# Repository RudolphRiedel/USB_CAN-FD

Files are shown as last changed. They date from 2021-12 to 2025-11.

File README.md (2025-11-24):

# Hardware
This is an Open Source Hardware USB to CAN-FD interface.
The design goal of this PCB was to provide two isolated CAN-FD channels capable of 8MBit/s for the data phase.

## D5035-01
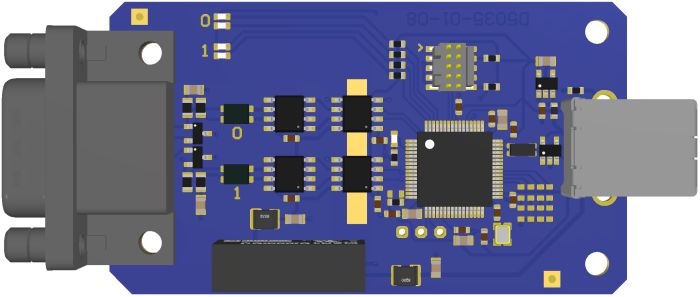
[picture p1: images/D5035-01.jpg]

The PCBs D5035-01-xx are based on the ATSAME51J microcontroller from Microchip.
Any ATSAME51J1x-Axx can be used, so every variant in TQFP-64, the bootloader and the firmware work on all three memory sizes.

D5035-01-08 likely is the final version.
I switched from using CAN-FD transceivers to CAN-SIC transceivers.

There is a full BOM included now: D5035-01_BOM_Release.xlsx
It has order codes from Mouser as example and the sum of the parts I selected came out as just below 29 Euros exclucding taxes when ordering only parts for a single unit.
The most expensive parts are the digital isolators, the controller, the CAN transceivers, the DCDC converter and the oscillator, which already cover more than half of the BOM costs which leaves no room to bringt the costs down - except when buying in bulk.
Cheaping out on components like the D-Sub 9 would be possible, but I really advise against it, I already chose a component that is inexpensive for it's specification, it is important for the application to use a gold plated D-Sub with at least 200 mating cycles.

The board is 69 mm x 39 mm.

## D5035-01-20
Almost the same as D5035-01-08, but with an USB-C connector.

## D5035-03
The PCB D5035-03-01 is designed as a carrier board for the Teensy 4.0.
This is more a prove of concept, a child of the current chip-shortage.

And it works, but it turned out to be rather fidgety to access the pins
for the single CAN-FD available and the 61 mm x 33 mm case does not work well for this version.

## D5035-05
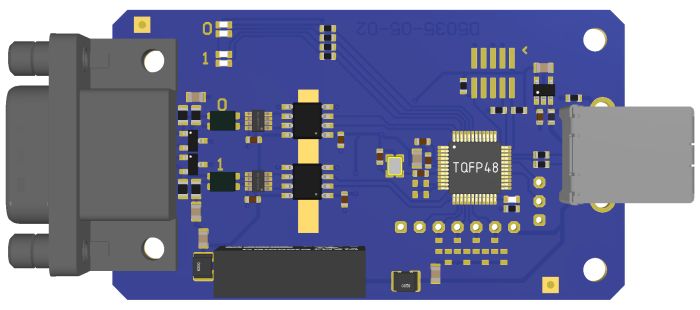
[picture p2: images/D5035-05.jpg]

The PCBs D5035-05-xx are based on the STM32G0B1CET6 microcontroller.
The board is slightly larger at 69 mm x 39 mm.

## Case
There are two versions of a 3D printable case available in this repository:
D5035-01 - 39 mm x 74.1 mm
D5035-05 - 45 mm x 82.14 mm

Assembly requires two press-fit light pipes for the status LEDs, two lengths of black 3.2 mm heat shrink tubing to hold the light pipes in place and four countersunk screws.

LFB063CTP - DigiKey LFB063CTP-ND - Mouser 593-LFB063CTP
M3 x 16 mm, countersunk, preferably Torx / A2 (ISO 14581)

## Whats next
There is an idea for a PCB with a different controller but unfortunately these are not
available anywhere, so this got pushed back.

## Beyond CAN
A board with 100Base-T1 or 10Base-T1S is also something we think about.

## Firmware
The open source firmware for this project is here: https://github.com/jgressmann/supercan

## Windows application
An open source Windows application that works with this interface is here: https://github.com/TDahlmann/canpp

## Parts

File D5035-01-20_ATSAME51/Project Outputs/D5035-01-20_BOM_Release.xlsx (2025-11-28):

Comment | Description | Designator | Footprint | Number | Mouser | Price [EUR] | Price sum | Alternative Part
10n | X7R/10V/10% | C100 | 0603 (1608 Metric) | 1 | 710-885012206014 | 0.095 | 0.095
100n | X7R/50V/10% | C101, C103, C104, C106, C107, C108, C111, C113, C115, C117, C118, C120 | 0603 (1608 Metric) | 12 | 603-CC603KRX7R9BB104 | 0.023 | 0.276
4µ7 | X5R/25V/10% | C102, C105, C109, C110, C112, C116 | 0805 (2012 Metric) | 6 | 187-CL21A475KAQNNNG | 0.095 | 0.57
4n7 | X7R/200V/10% | C114, C119 | 0805 (2012 Metric) | 2 | 187-CL21B472KDCNNNC | 0.095 | 0.19
D1213A-02SM-7 | ESD Protection Diode Array | D100 | SOT23-5 | 1 | 621-D1213A-02SM-7 | 0.292 | 0.292 | WE 824011
PESD1CAN | ESD Protection Diode Array | D105, D107 | SOT23 | 2 | 511-ESDCAN01-2BLY | 0.15 | 0.3 | 771-PESD1CAN-T/R
green | 100+ mcd | D106, D108, D110 | 0603 (1608 Metric) | 3 | 710-150060GS75000 | 0.138 | 0.414 | 859-LTST-C191TGKT
red | 100+ mcd | D109, D111 | 0603 (1608 Metric) | 2 | 710-150060RS75000 | 0.138 | 0.276 | 859-LTST-C190KRKT
TG2520SMN16.0000M-MCGNNM | Oscillator 16MHz, 3.3V, 0.5PPM | G100 | 2,5mm x 2,0mm | 1 | 732-2520SMN16MCGNNM0 | 0.628 | 0.628
BBPY0016080301Y00 | Ferrite Bead | L100 | 0603 (1608 Metric) | 1 | 710-742792641 | 0.143 | 0.143 | WE 742792641
PE-1206CCMC900STS | USB Common Mode Choke | L101 | 3216 | 1 | 673-PE-1206CCMC900ST | 0.542 | 0.542 | WE 744232090
82103C | 10µH/500mA Power Inductor | L102, L103 | 1210 (3225 Metric) | 2 | 963-LBC3225T100KR | 0.103 | 0.206 | LBC3225T100KR
SRF3225TAC-101Y | CAN Commen Mode Choke | L104, L105 | 1210 (3225 Metric) | 2 | 652-SRF3225TAC-101Y | 0.507 | 1.014
10k | 1%/TK100 | R111, R112, R115, R116 | 0603 (1608 Metric) | 4 | 603-RT0603FRE1310KL | 0.095 | 0.38
2k | 1%/TK100 | R105, R107 | 0603 (1608 Metric) | 2 | 594-MCT06030C2001FP5 | 0.095 | 0.19
1k | 1%/TK100 | R106, R108 | 0603 (1608 Metric) | 2 | 603-AT0603FRE071KL | 0.093 | 0.186
4k7 | 1%/TK100 | R109, R110, R113, R114, R100, R118 | 0805 (2012 Metric) | 6 | 603-RT0805FRE074K7L | 0.095 | 0.57
ATSAME51J18A-AU | MicroController, CAN-FD/USB | U100 | TQFP64-0.5mm | 1 | 556-ATSAME51J18AAU | 4.76 | 4.76 | ATSAME51J19A-AU
MIC5317-3.3YD5 | LDO, 3.3V, 150mA | U101 | SOT23-5 | 1 | 998-MIC5317-3.3YD5TR | 0.215 | 0.215
TEA 1-0505E | Isolated DC/DC 1W, 5V in, 5V out, 200mA | U102 | 4Pin SIP | 1 | 495-TEA1-0505E | 1.44 | 1.44 | MER1S0505SC
TCAN1462VDRQ1 | CAN SIC Transceiver 8 Mb/s | U103, U105 | SO8 | 2 | 595-TCAN1462VDRQ1 | 1.11 | 2.22 | TCAN1462DRQ1
SI8621EC-B-IS | Digital Isolator, 3.75kV, 150 Mb/s | U104, U106 | SO8 | 2 | 634-SI8621EC-B-ISR | 2.2 | 4.4
UJ20-C-H-G-SMT-1-P16-TR | USB Type C Connector, 16P | X100 | USB-C | 1 | 179-UJ20CHGSMT1P16TR | 0.456 | 0.456
D09P13A4PV00LF | D-Sub 9, Female, Right Angle, 200+ Mating cycles | X102 | D-Sub | 1 | 649-D09P13A4PV00LF | 1.36 | 1.36 | D09P13B6GV00LF
SWD | SMD pin header | X104 | 2x5 1,27mm | 1 | 649-200211210010C1LF | 0.662 | 0.662 | 649-221121-00010T4LF
LFB063CTP | Light Pipe | Mechanical | 15.9 mm x 2.84 mm | 2 | 593-LFB063CTP | 0.645 | 1.29
M3x16 | Screw ISO 14581 – countersunk, Torx, A2 | Mechanical |  | 4
D5035-02_top.stl | Case, 3D printed | Mechanical | 82 mm x 45 mm x 17 mm | 1
D5035-02_bottom.stl | Case, 3D printed | Mechanical | 82 mm x 45 mm x 12 mm | 1
 |  |  |  |  |  |  | 23.075
prices: | worst case, single unit | Checked: 2025-02-20
 |  | Checked: 2025-11-24

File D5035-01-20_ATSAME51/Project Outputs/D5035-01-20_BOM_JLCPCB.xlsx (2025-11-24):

Comment | Designator | Footprint | JLCPCB Part #
10n | C100 | 0603 | C57112
100n | C101, C103, C104, C106, C107, C108, C111, C113, C115, C117, C118, C120 | 0603 | C14663
4µ7 | C102, C105, C109, C110, C112, C116 | 0805 | C1779
4n7 | C114, C119 | 0805 | C1744
D1213A-02SM-7 | D100 | SOT23-5 | not available
PESD1CAN | D105, D107 | SOT23 | C343993
green | D106, D108, D110 | 0603 | C19171301
red | D109, D111 | 0603 | C2286
TG2520SMN16.0000M-MCGNNM | G100 | 2,5mm x 2,0mm | do not populate
BBPY0016080301Y00 | L100 | 0603 | not available
PE-1206CCMC900STS | L101 | 3216 | not available
82103C | L102, L103 | 3,2x2,5 mm | not available
SRF3225TAC-101Y | L104, L105 | 3225 | not available
10k | R111, R112, R115, R116 | 0603 | C25804
2k | R105, R107 | 0603 | C22975
1k | R106, R108 | 0603 | C21190
4k7 | R109, R110, R113, R114, R100, R118 | 0805 | C17673
SAME51J18A-AU | U100 | TQFP64-0.5mm | not available
MIC5317-3.3YD5 | U101 | SOT23-5 | not available
TEA 1-0505E | U102 | 4Pin SIP | not available
TCAN1462VDRQ1 | U103, U105 | SO8 | not available
SI8621EC-B-IS | U104, U106 | SO8 | (C461877)-outofstock
USB-C | X100 | USB-C | C2765186
9651226803 | X102 | D-Sub | do not populate
SWD | X104 | 2x5 1,27mm | do not populate

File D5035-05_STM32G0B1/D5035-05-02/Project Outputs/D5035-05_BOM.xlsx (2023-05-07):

Comment | Designator | Footprint | JLCPCB Part #
10n | C100 | 0603 | C57112
100n | C101, C102, C105, C106, C111, C112, C114, C115 | 0603 | C14663
4µ7 | C103, C104, C107, C108 | 0805 | C1779
4n7 | C110, C113 | 0805 | C1744
green | D104, D105, D107 | 0603 | C72043
red | D106, D108 | 0603 | C2286
PESD1CAN | D109, D110 | SOT23 | C343993
16MHz | G100 | 2,5mm x 2,0mm | do not populate
WE_742792641 | L100 | 0603 | do not populate
xx82103C | L101, L102 | 3,2x2,5 mm | do not populate
DLW32SH101XF2L‎ | L103, L104 | 3225 | do not populate
22R | R102, R103 | 0603 | C22950
10k | R105, R106, R115, R116, R120 | 0603 | C25804
2k | R111, R113 | 0603 | C22975
1k | R112, R114 | 0603 | C21190
4k7 | R118, R119, R121, R122 | 0805 | C17673
STM32G0B1CET6 | U100 | TQFP48-0.5mm
MIC5317-3.3YD5 | U101 | SOT23-5 | do not populate
MER1S0505SC | U102 | 4Pin SIP | do not populate
TCAN1044V | U103, U105 | SOT23-8 | do not populate
SI8621EC-B-IS | U104, U106 | SO8 | C461877
61729-0010BLF | X101 | USB-B | do not populate
9651226803 | X103 | D-Sub | do not populate

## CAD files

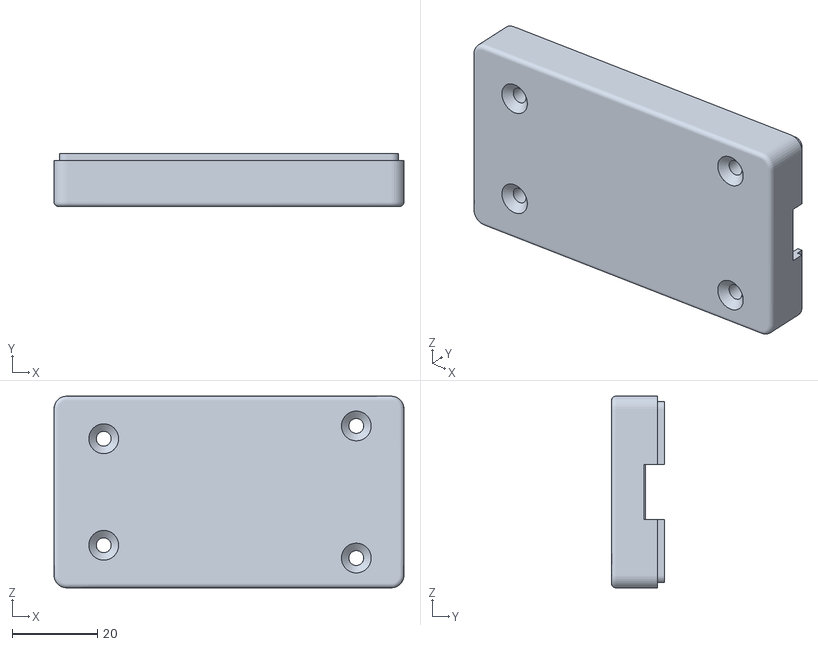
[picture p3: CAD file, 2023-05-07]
Case/D5035-05_bottom.stl
82.1 x 12.4 x 45.0

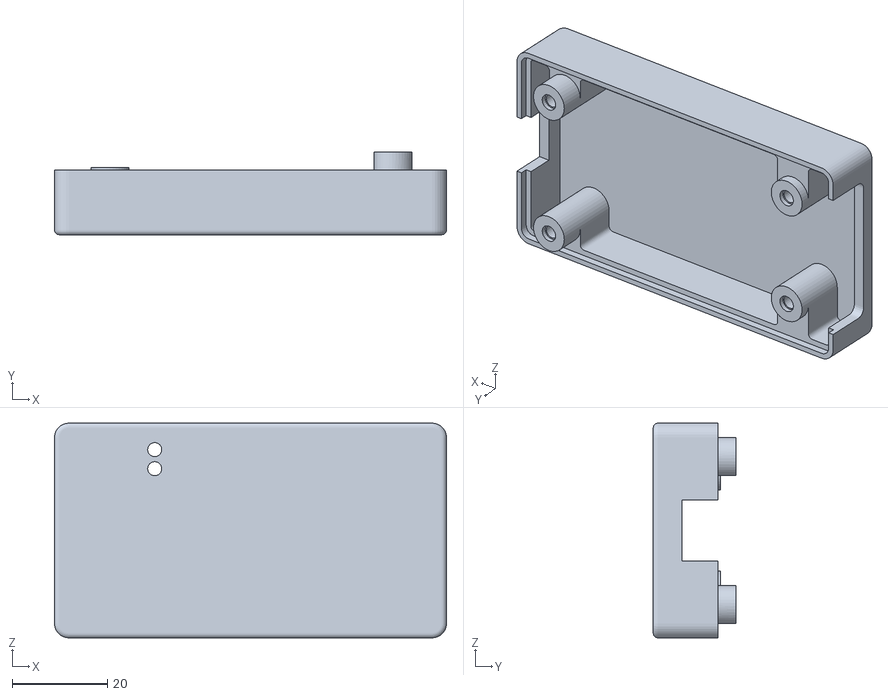
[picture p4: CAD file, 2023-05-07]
Case/D5035-05_top.stl
82.1 x 17.3 x 45.0

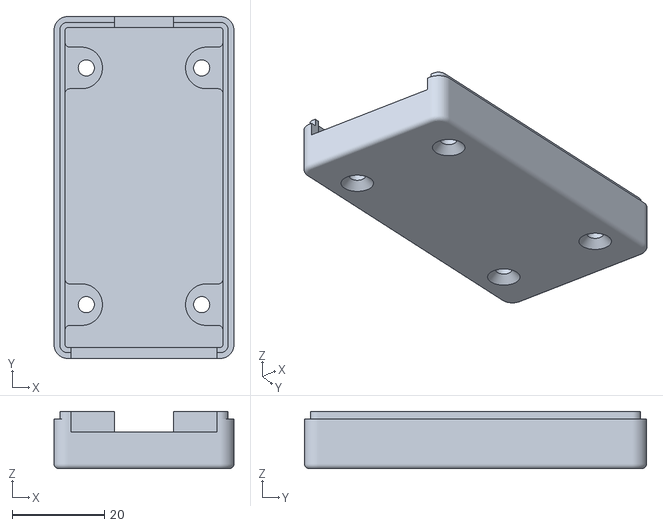
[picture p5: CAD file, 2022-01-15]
Case/D5035-01_bottom.stl
39.0 x 74.1 x 12.4

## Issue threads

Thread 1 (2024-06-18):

Can you please create a step-by-step firmware building and downloading?

toneytang, 2024-06-18:
Thank .

RudolphRrr, 2024-06-25:
Oh? Only saw this by chance, I have not seen a notification for this issue.

This repository does not have any frmware as this is a collaboration, check out: https://github.com/jgressmann/supercan

Downloading the firmware depends on the variant, for ATSAME51 I open Microchip Studio and flash the Supercan bootloader with either an Atmel ICE or a Segger JLink.
With the STM32G0B1 variant the firmware is just flashed with DFU-Util as the STM32 already has an USB bootloader built in.

zerotoney, 2024-10-10:
Thank you. I will give it a try. Still frustrated where to get the whole firmware project. New guy to STM.

toneytang, 2024-10-15:
https://github.com/jgressmann/tinyusb/tree/master/examples/device/supercan

Closed 2024-10-15.

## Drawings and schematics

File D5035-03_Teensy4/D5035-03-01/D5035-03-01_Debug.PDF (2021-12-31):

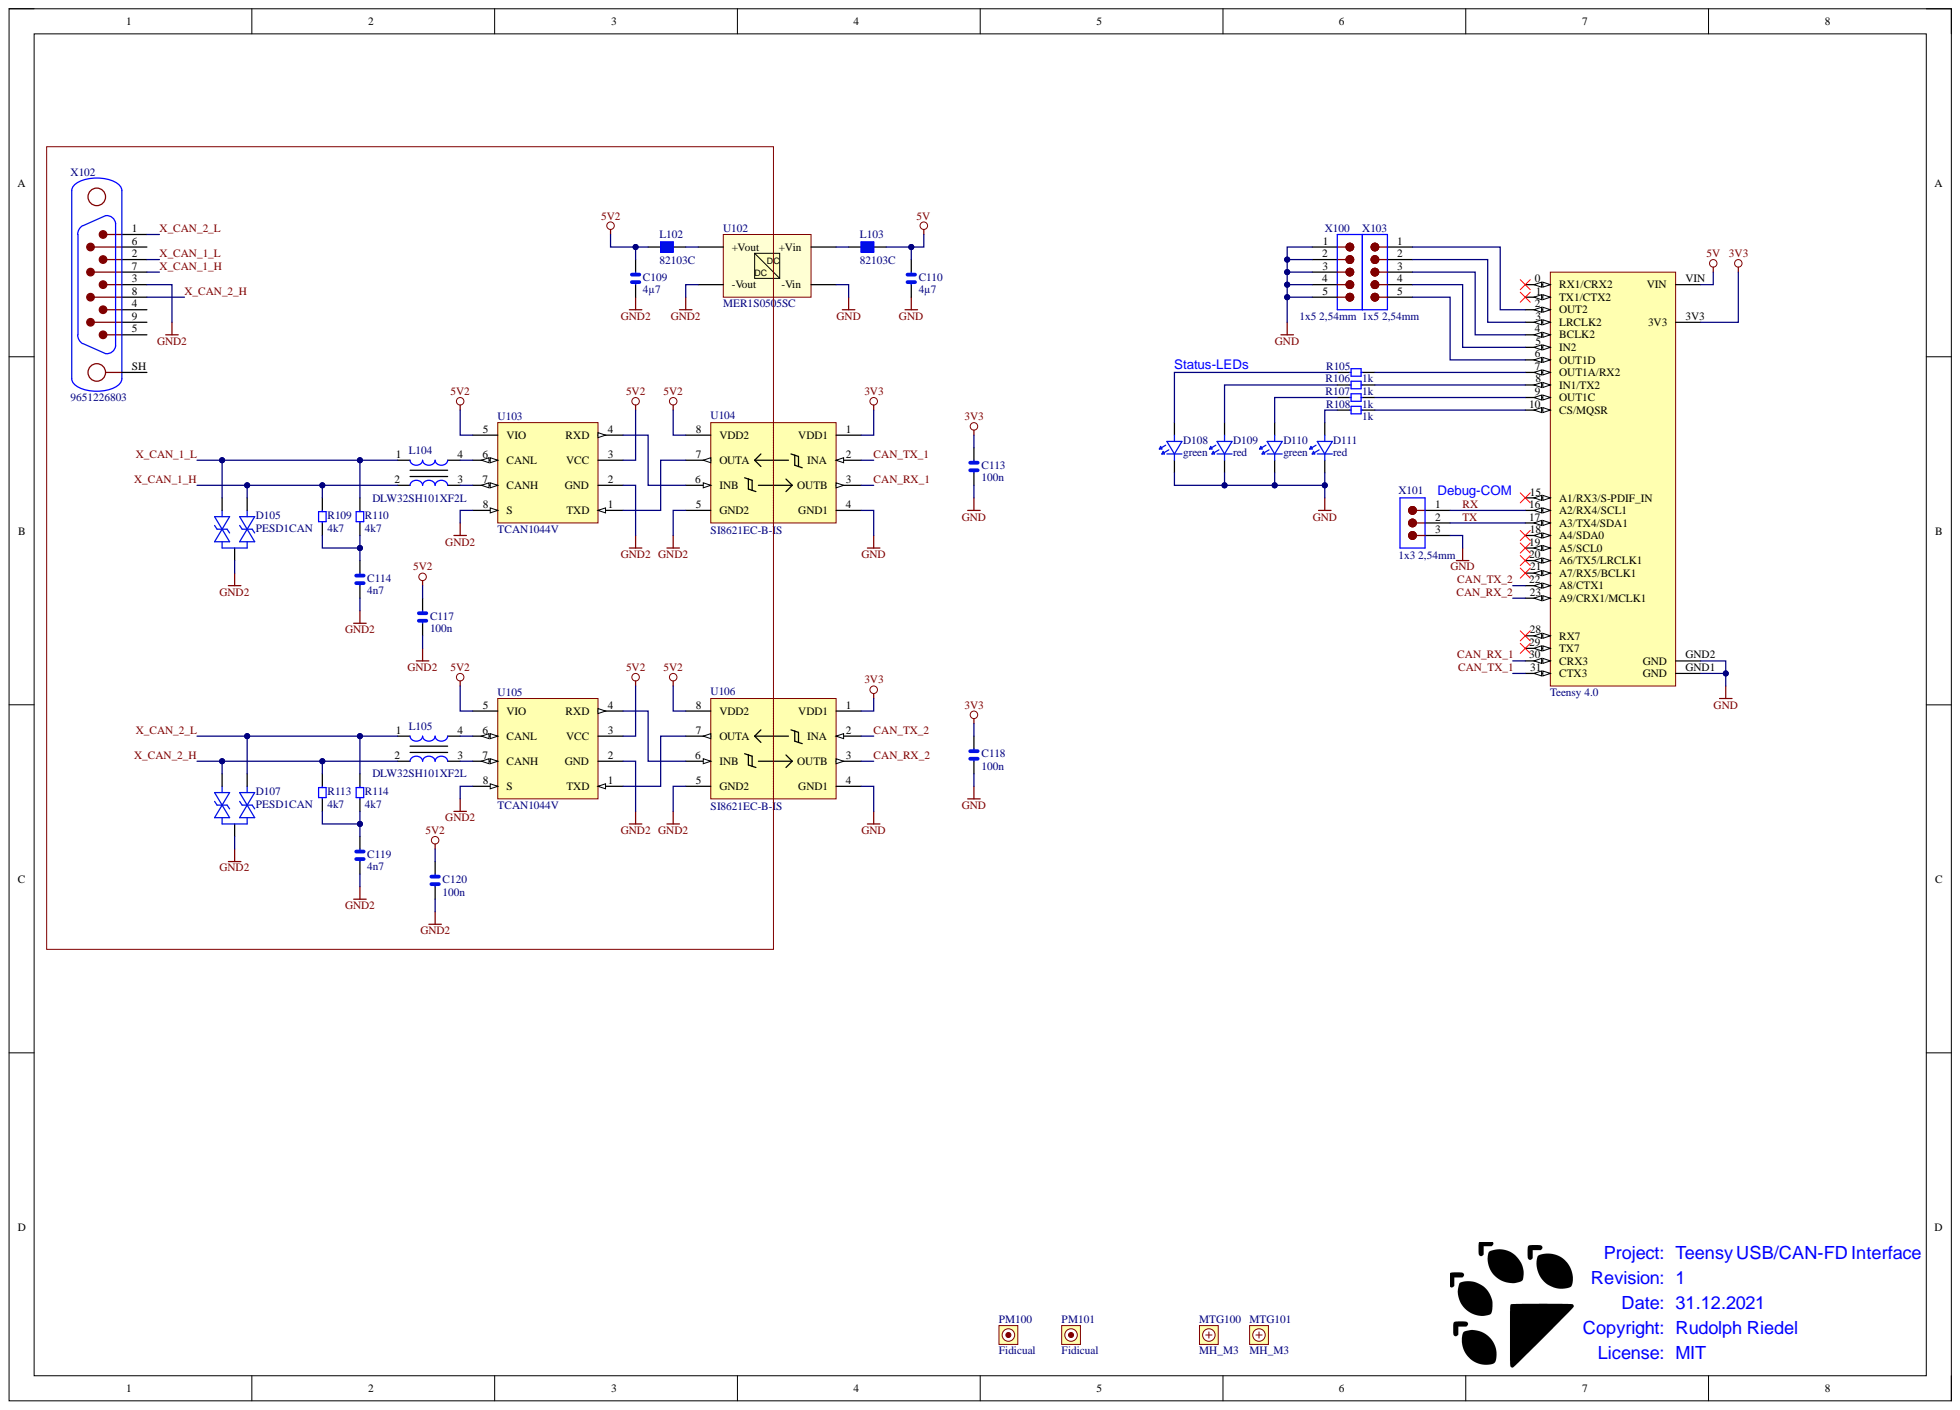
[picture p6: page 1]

LRCLK2 3

Project: Teensy USB/CAN-FD Interface
Revision: 1
Date: 31.12.2021
Copyright:
License:

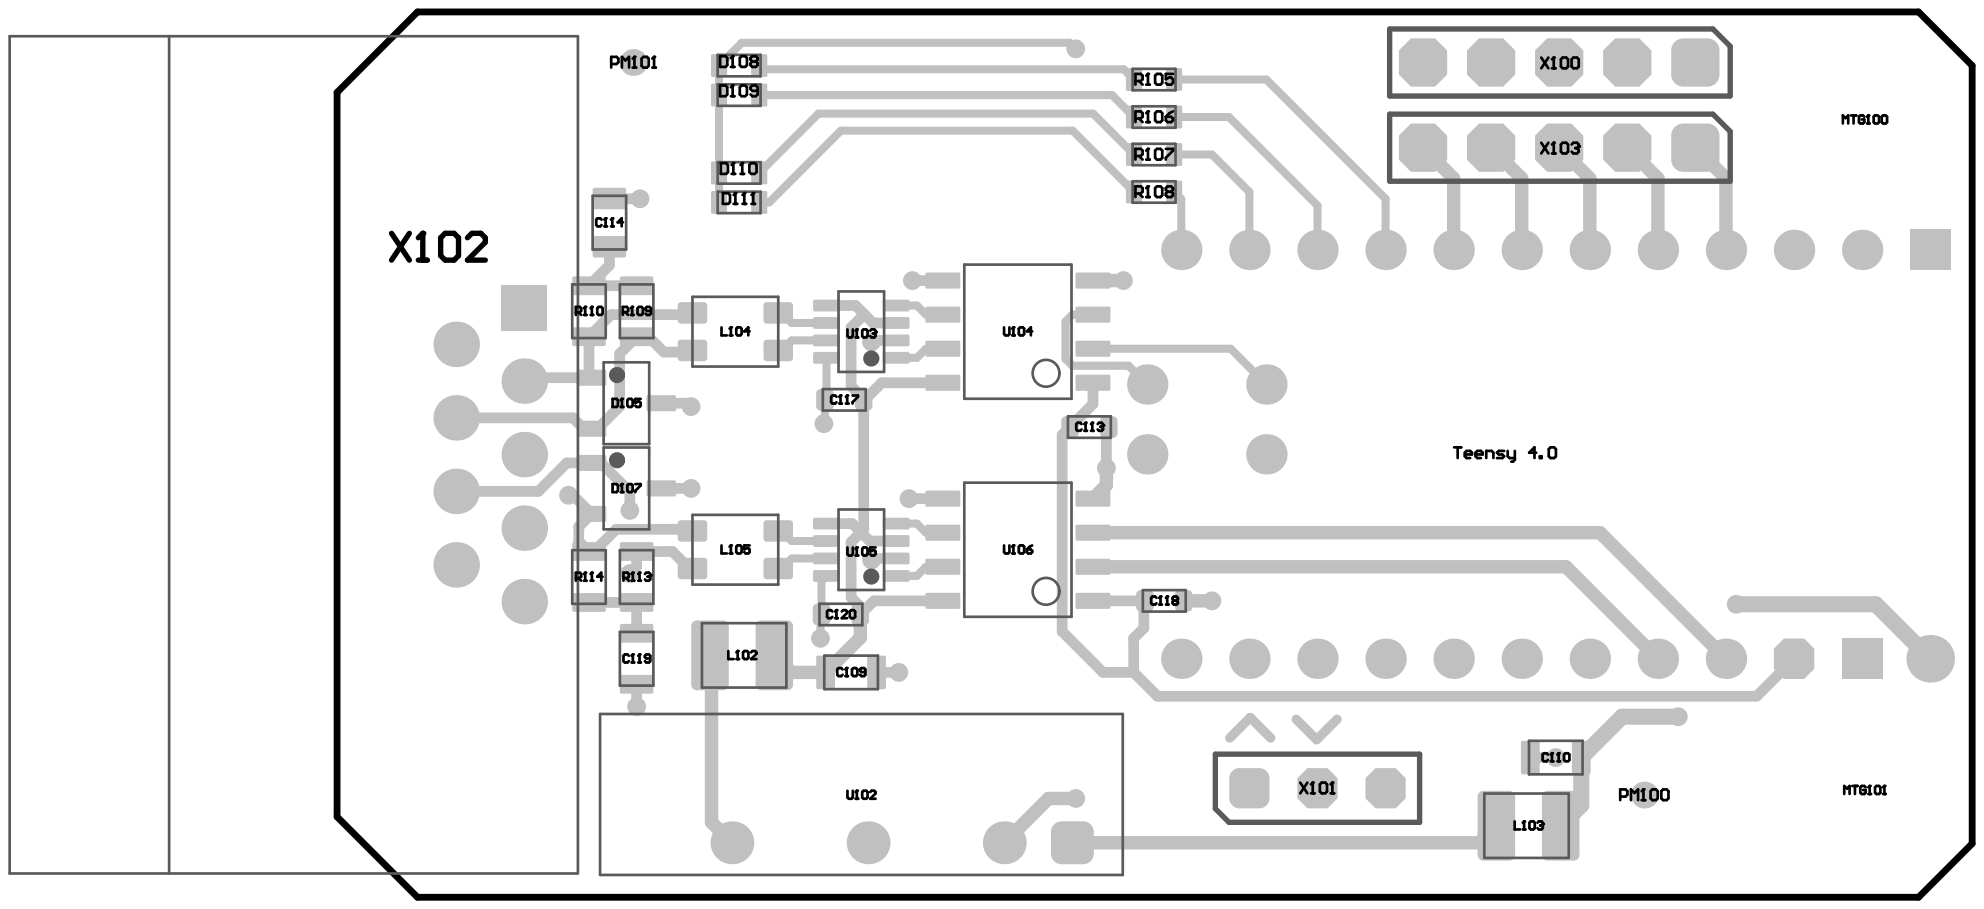
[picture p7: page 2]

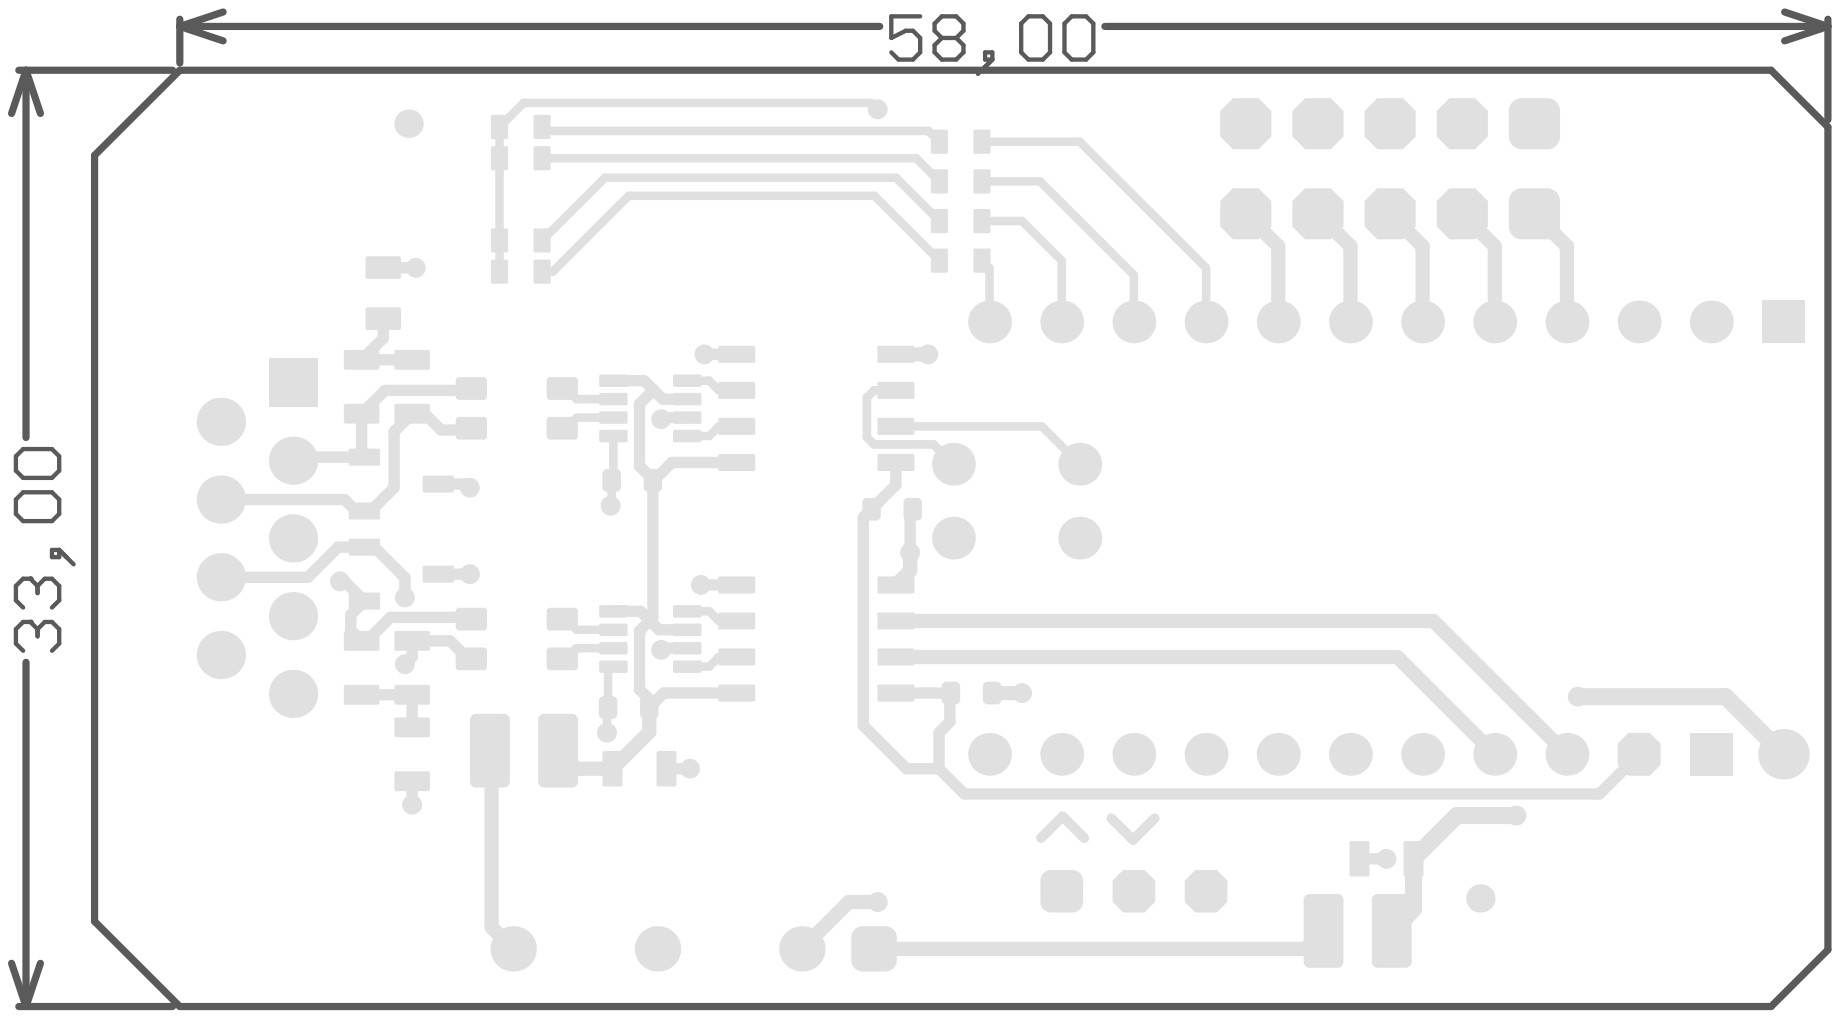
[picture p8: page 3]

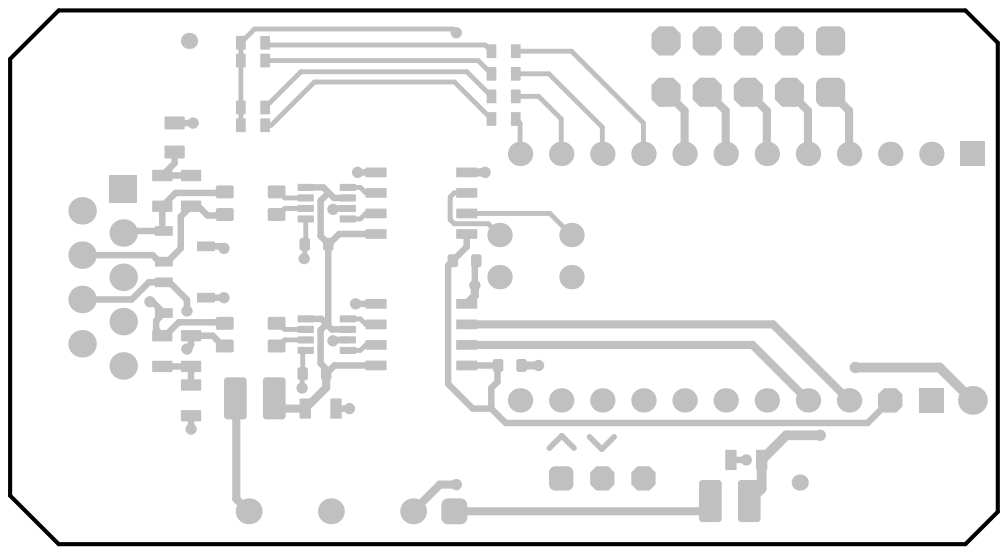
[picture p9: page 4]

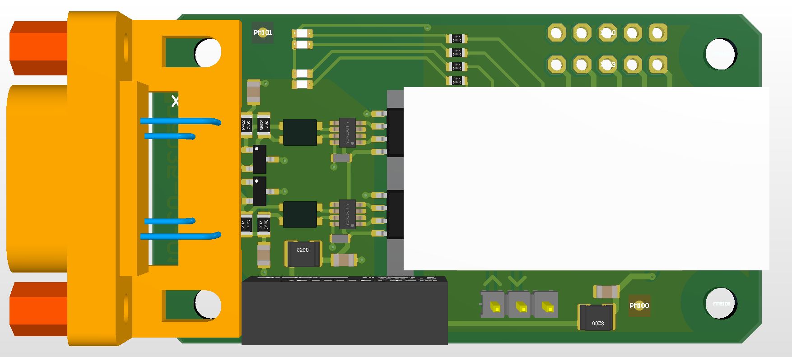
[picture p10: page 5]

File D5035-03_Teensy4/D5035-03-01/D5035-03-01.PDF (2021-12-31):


LRCLK2 3

Project: Teensy USB/CAN-FD Interface
Revision: 1
Date: 31.12.2021
Copyright:
License:




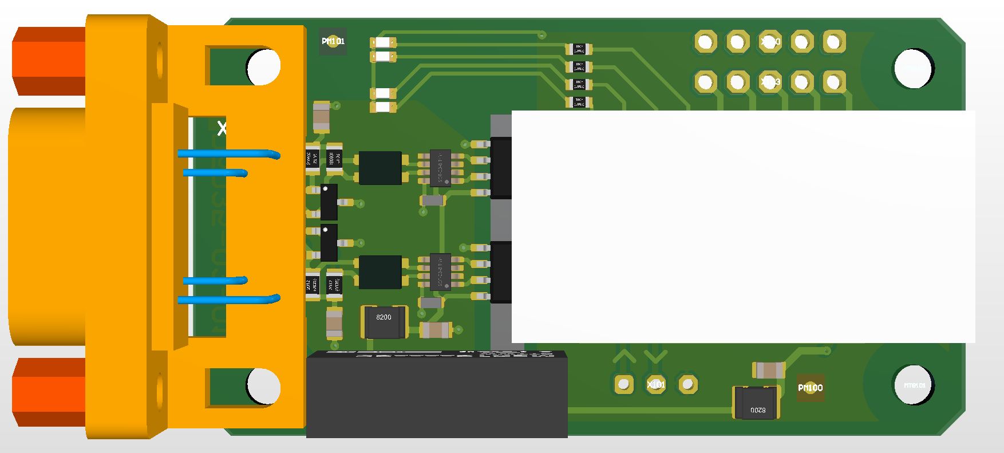
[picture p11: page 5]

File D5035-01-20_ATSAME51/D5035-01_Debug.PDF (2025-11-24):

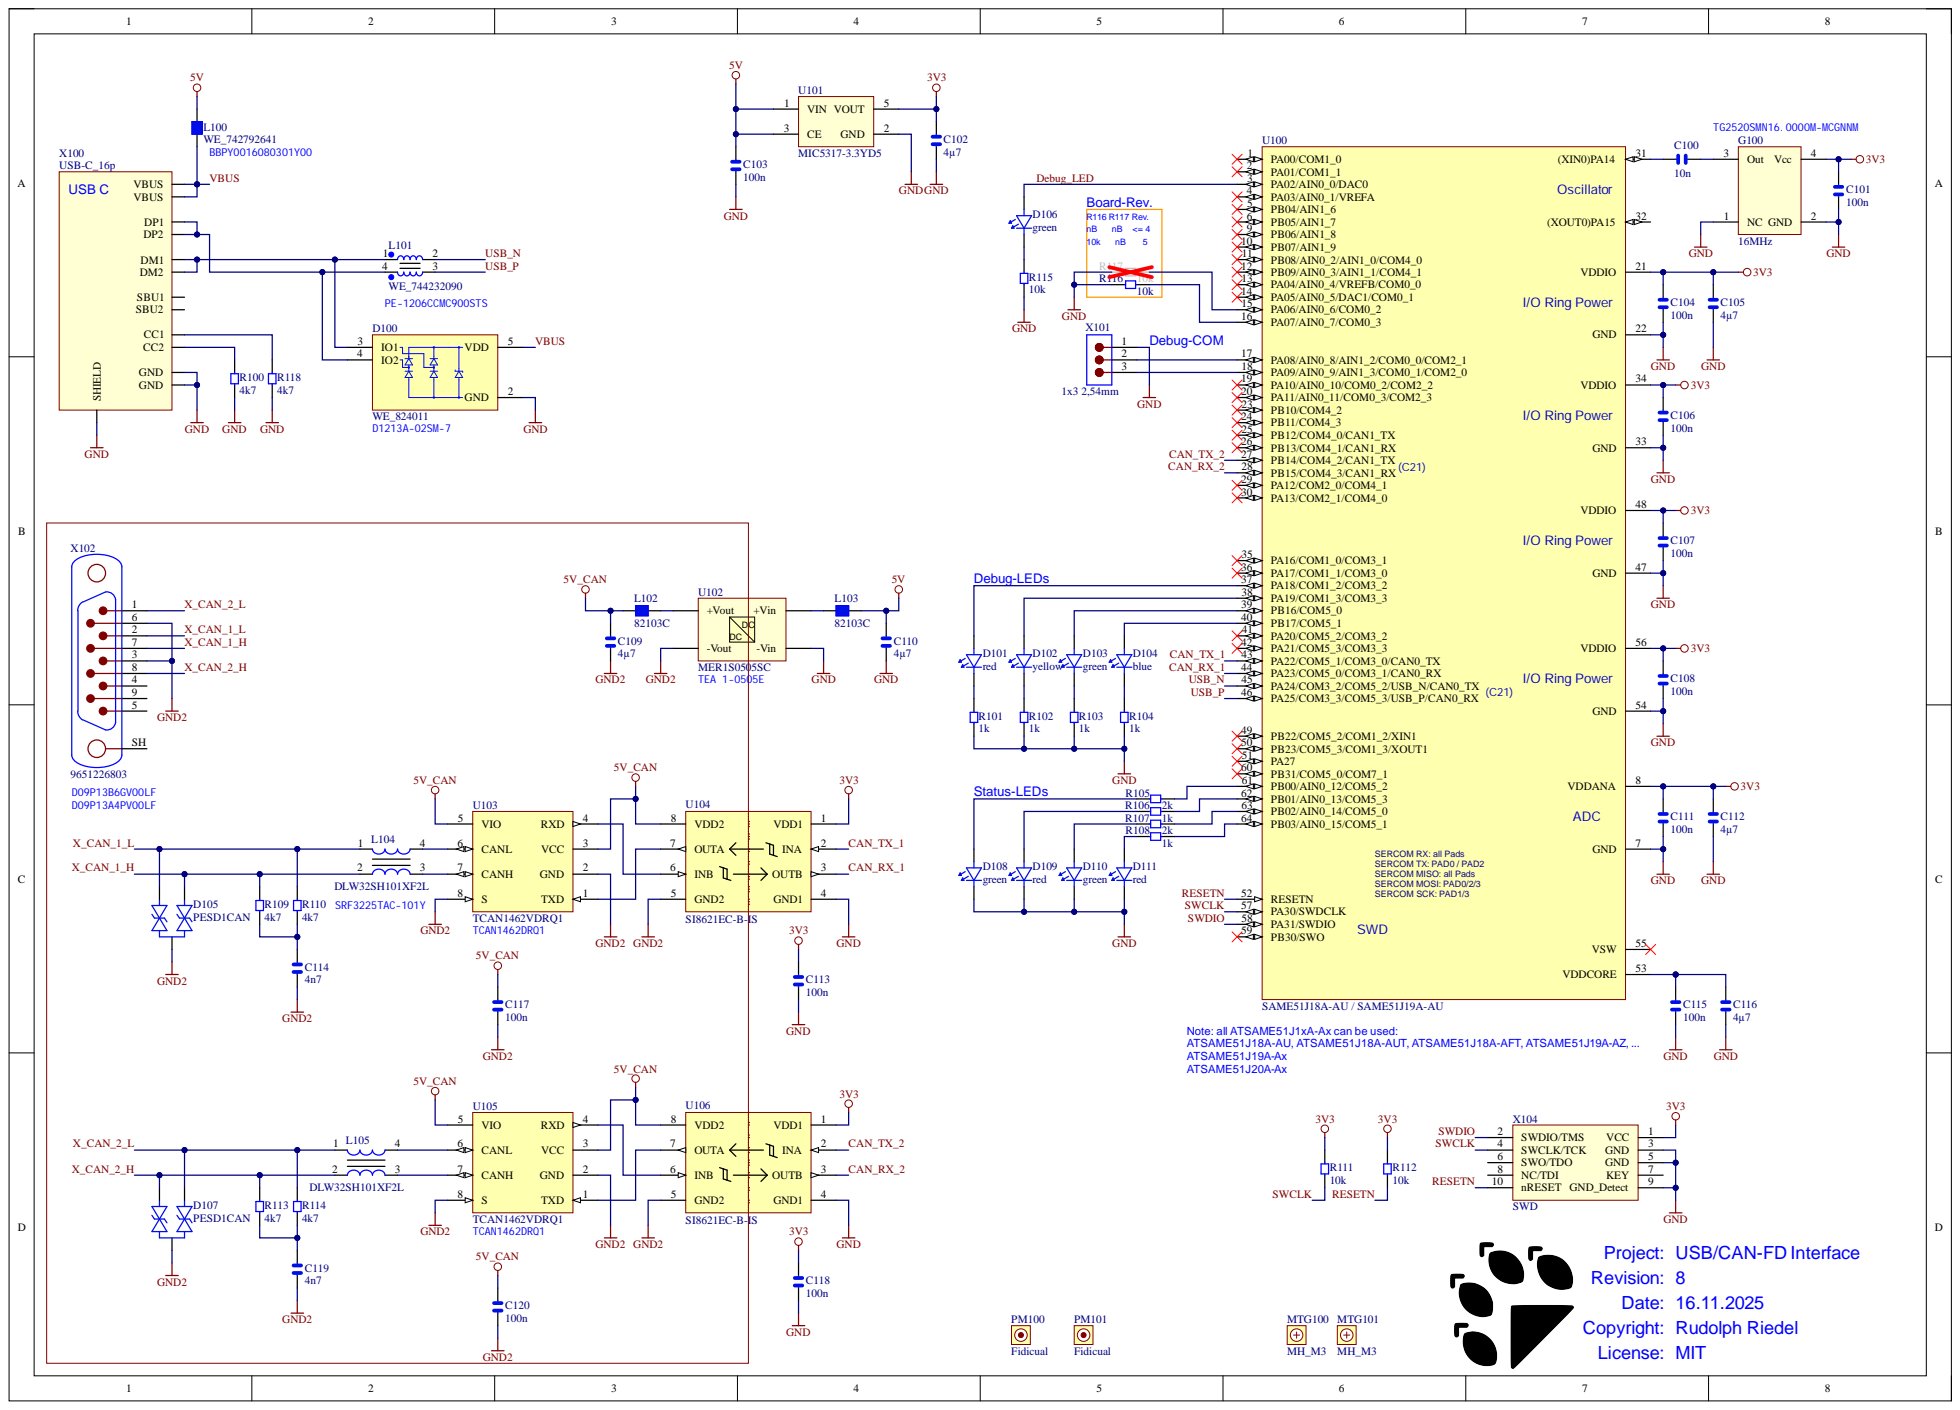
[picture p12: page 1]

PA19/COM1_3/COM3_3 38

PB17/COM5_1 40

PA21/COM5_3/COM3_3 42

5V_CAN

PB02/AIN0_14/COM5_0 63

SERCOM RX: all Pads
SERCOM TX: PAD0 / PAD2
SERCOM MISO: all Pads
SERCOM MOSI: PAD0/2/3
SERCOM SCK: PAD1/3

Note: all ATSAME51J1xA-Ax can be used:
ATSAME51J18A-AU, ATSAME51J18A-AUT, ATSAME51J18A-AFT, ATSAME51J19A-AZ, ...
ATSAME51J19A-Ax
ATSAME51J20A-Ax

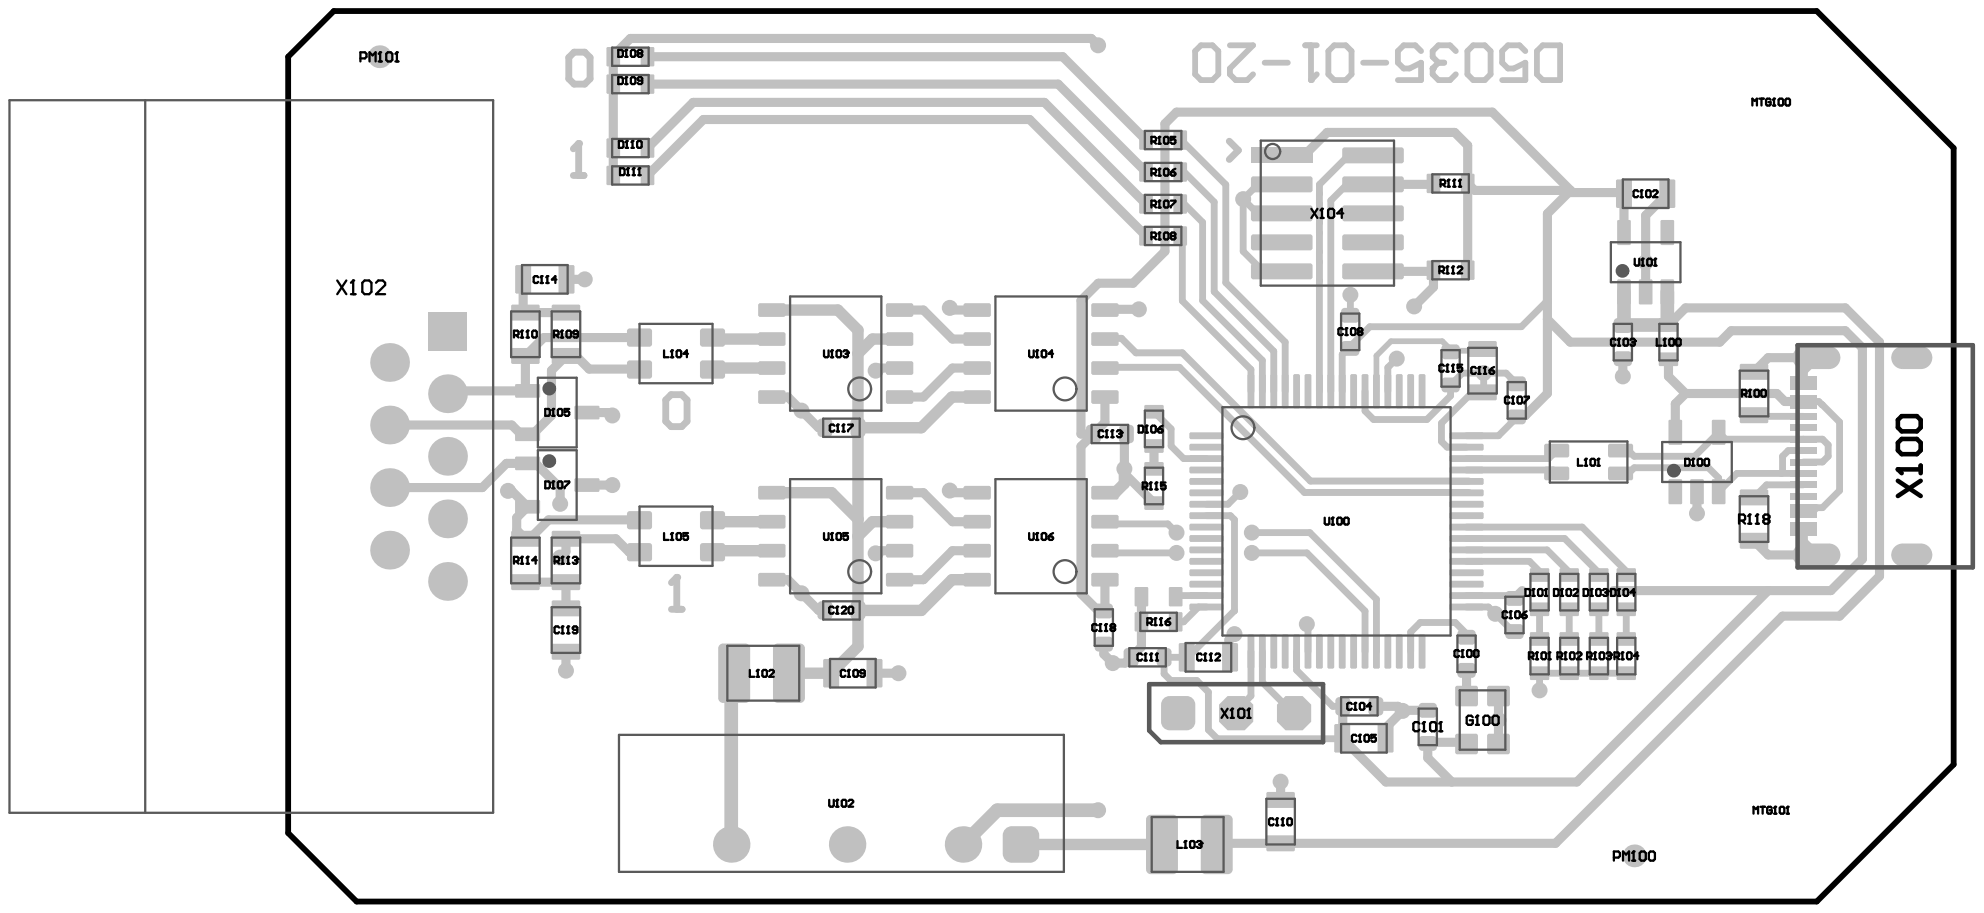
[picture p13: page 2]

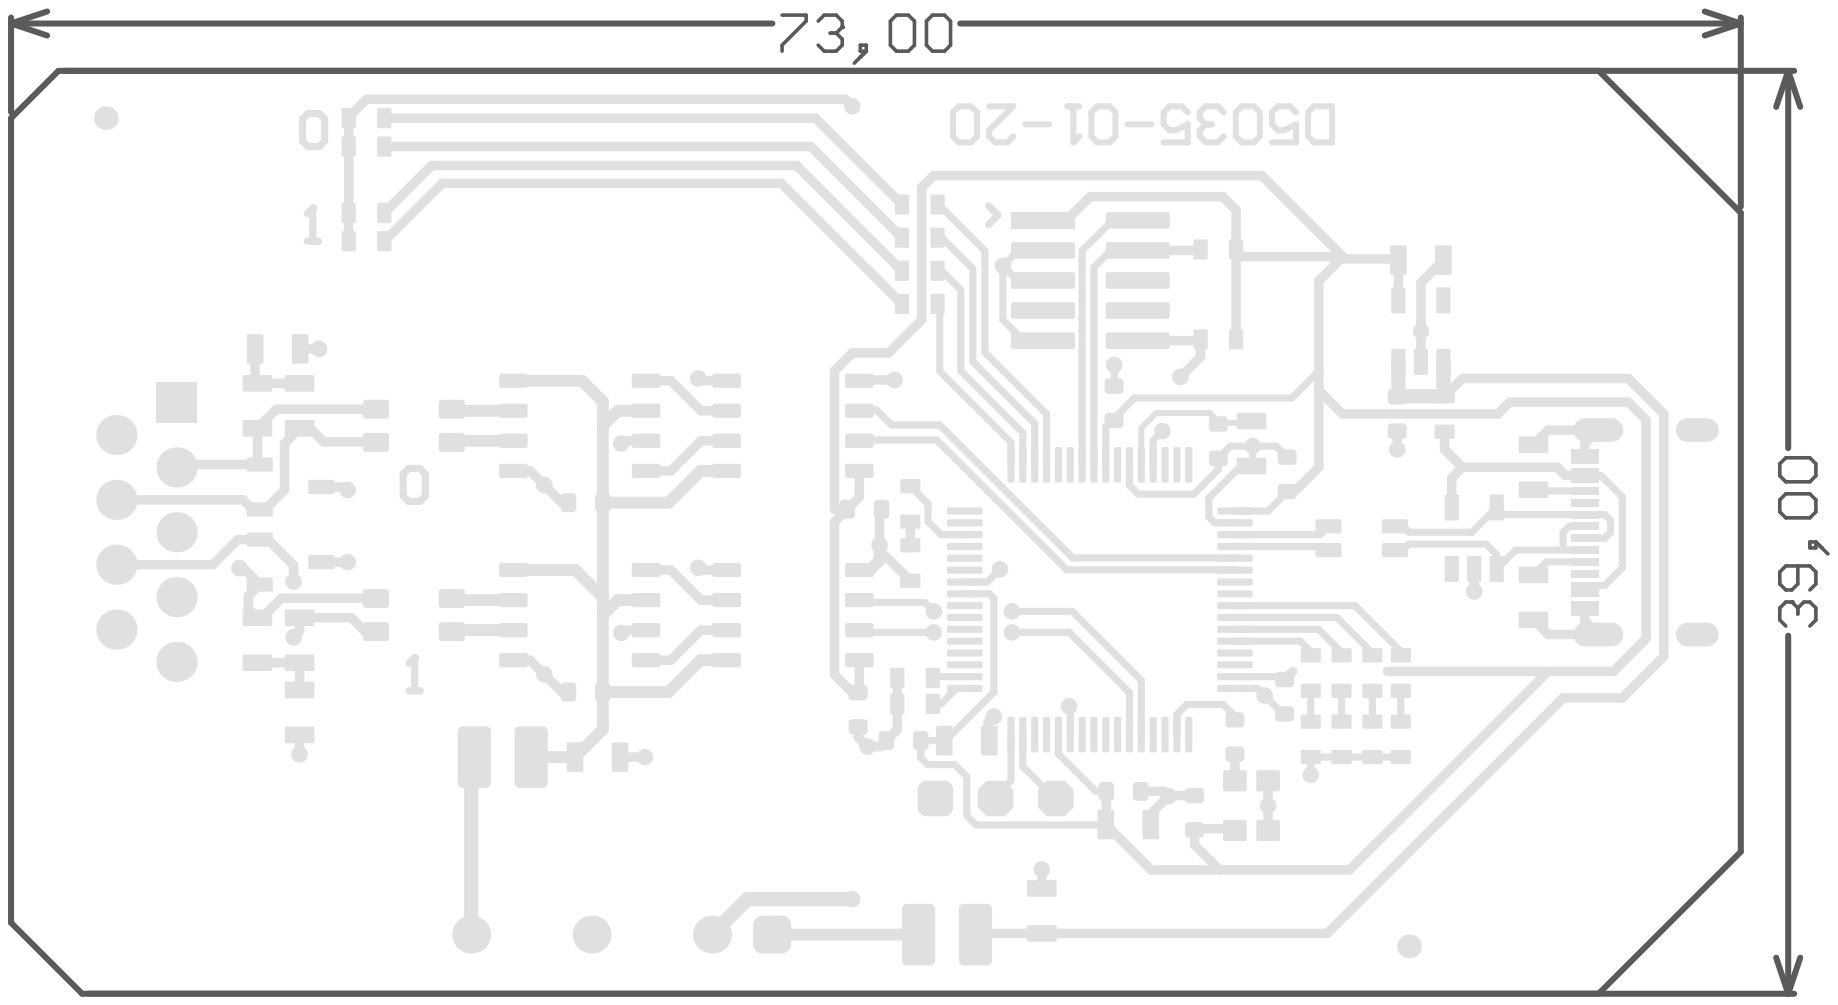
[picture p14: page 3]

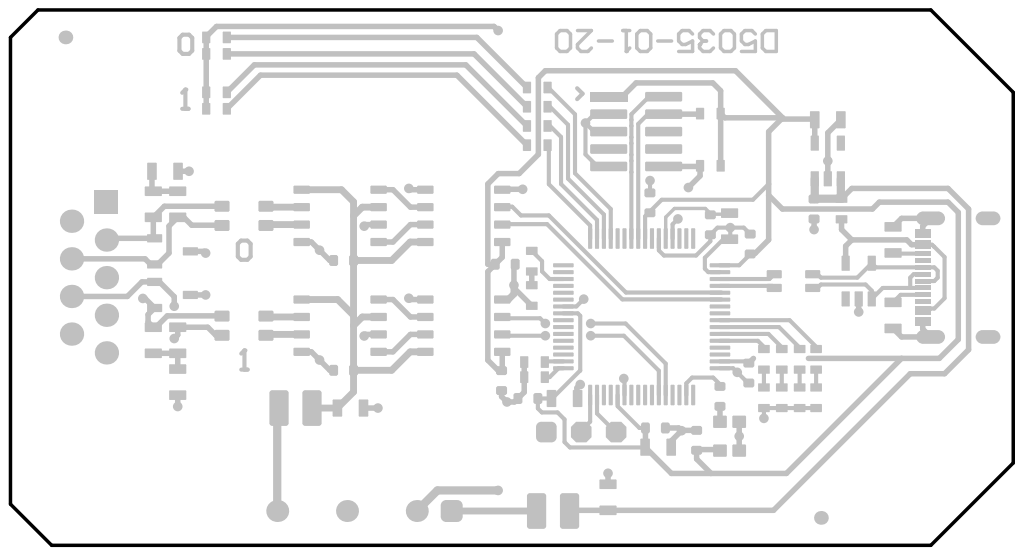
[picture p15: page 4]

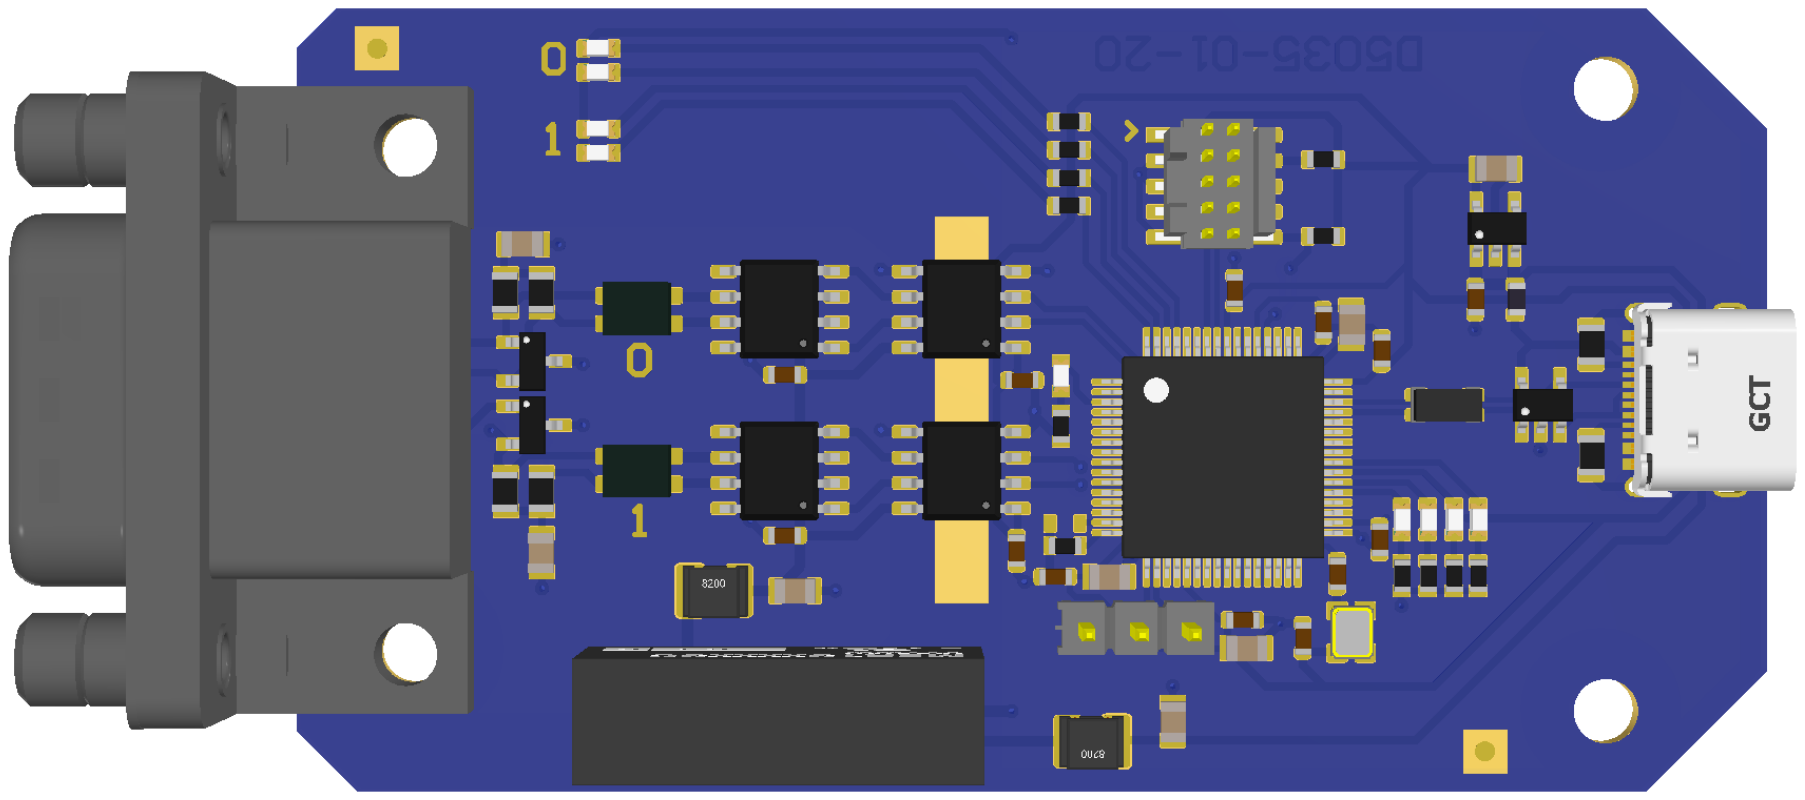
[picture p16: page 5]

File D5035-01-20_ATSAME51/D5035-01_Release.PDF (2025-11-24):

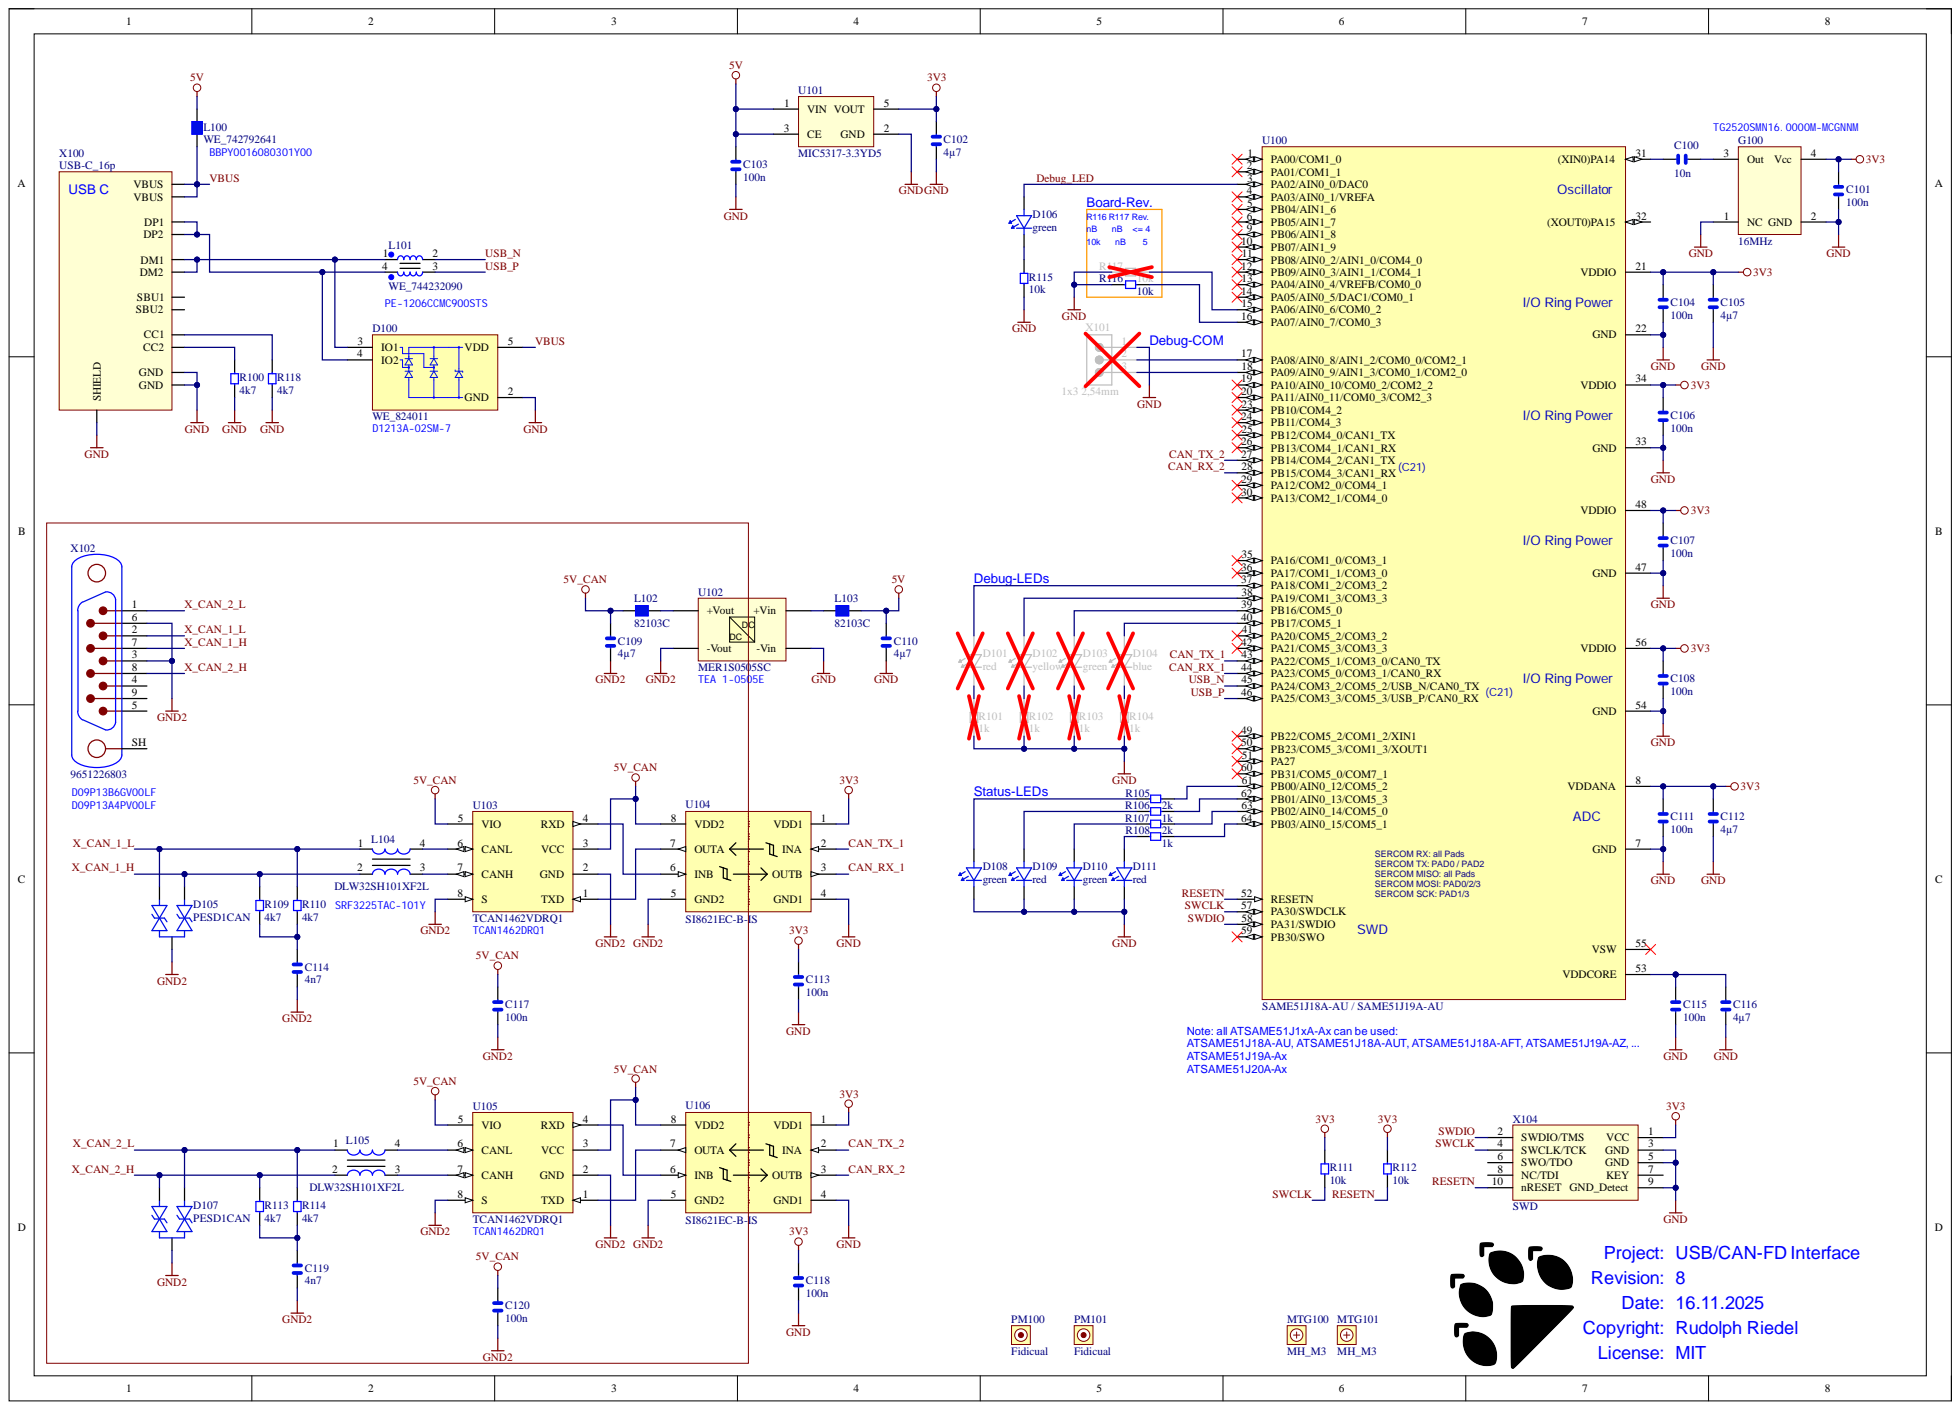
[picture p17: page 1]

PA19/COM1_3/COM3_3 38

PB17/COM5_1 40

PA21/COM5_3/COM3_3 42

5V_CAN

PB02/AIN0_14/COM5_0 63

SERCOM RX: all Pads
SERCOM TX: PAD0 / PAD2
SERCOM MISO: all Pads
SERCOM MOSI: PAD0/2/3
SERCOM SCK: PAD1/3

Note: all ATSAME51J1xA-Ax can be used:
ATSAME51J18A-AU, ATSAME51J18A-AUT, ATSAME51J18A-AFT, ATSAME51J19A-AZ, ...
ATSAME51J19A-Ax
ATSAME51J20A-Ax





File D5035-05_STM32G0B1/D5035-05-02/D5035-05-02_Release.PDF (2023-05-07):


PA4/ADC_IN4/SPI2_MOSI/DAC1_OUT1 15
PA5/ADC_IN5/SPI1_SCK/DAC1_OUT2 16
PA6/ADC_IN6/SPI1_MISO 17
PA7/ADC_IN7/SPI1_MOSI 18

CAN_RX_2 | PB0/ADC_IN8/FDCAN2_RX 19





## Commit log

2020-07-21 First commit to make this officially open source.
    [D5035-01.PrjPcb, D5035-01.SchDoc, D5035-01.xlsx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]
2020-07-22 - Added .stl files for a 3D-printable Case - minor tweaks to the schematic - modified the .readme with a link to the software
    [D5035-01.SchDoc, D5035-01_bottom.stl]
2021-02-27 ordered a bunch of partly populated PCBs from JLCPCB, added the BOM and CPL files
    [D5035-01_BOM.xlsx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]
2021-02-27 ordered parts and adjusted the BOM to what I actually ordered
    [D5035-01.xlsx]
2021-10-31 added D5035-01-04, D5035-03-01
    [D5035-01.PrjPcb, D5035-01.SchDoc, D5035-01.xlsx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]
2021-12-09 updated with D5035-01-05
    [D5035-01.PrjPcb, D5035-01.SchDoc, D5035-01.xlsx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]
2021-12-12 minor update
    [D5035-01.SchDoc]
2021-12-31 updated schematics template
    [D5035-01.PrjPcb, D5035-01.SchDoc, D5035-03.PrjPcb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]
2022-01-15 added holes for lightpipes to the top case, massively decreased the amount of triangles to a more sane amount
    [D5035-01_bottom.stl]
2023-05-07 - added D5035-05_STM32G0B1
    [D5035-01.PrjPcb, D5035-01.SchDoc, D5035-01.xlsx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]
2024-07-06 - D5035-01-08, likely to be the final release for D5035-01
    [D5035-01.PrjPcb, D5035-01.SchDoc, D5035-01.xlsx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]
2025-01-02 - fix: removed the overlay from the ODB++ data as the board is not supposed to be produced with a silkscreen
2025-01-02 - added ODB++ settings to project file
    [D5035-01.PrjPcb]
2025-02-20 - re-checked parts and prices, removed JLCPB column
    [D5035-01_BOM_Release.xlsx]
2025-11-24 - added D5035-01-20
    [D5035-01-20_BOM_JLCPCB.xlsx, D5035-01-20_BOM_Release.xlsx, D5035-01.PrjPcb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]
2025-11-28 - fix: forgot to adjust the amount for two resistors
    [D5035-01-20_BOM_Release.xlsx]
